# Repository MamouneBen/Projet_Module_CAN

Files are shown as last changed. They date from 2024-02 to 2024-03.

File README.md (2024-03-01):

# Logiciel :
**contient tous les éléments logiciels/programmations de ce projet**
-envoie de trame CAN
-conversion analogique

# Matériel : 
**contient tous les éléments physique de ce projet.**
-PCB
-Liste capteurs
-Liste pièces

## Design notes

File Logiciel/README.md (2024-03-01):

# ESP32-C3_Sender
code : c
framework : platformino
description : envoie can sur en c 

# ESP32Arduino
code : arduino (c++)
framework : platformino
description : envoie can sur en c++

# MCP3221
code : arduino (c++)
framework : platformino
description : conversion analogique à nunérique

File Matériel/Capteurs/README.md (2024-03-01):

# Capteurs 0-5V automobile
download

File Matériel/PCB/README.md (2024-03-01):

# PCB
framework : kicad 7.0

CapturePCB

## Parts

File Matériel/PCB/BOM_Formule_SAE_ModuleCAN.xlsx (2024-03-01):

Bill of Material
Board | Module_CAN |  | Concepteur Principal |  | Carl-Dominic Aubin |  |  | 1 | 00
Cours | Projet_Fin_DEC |  | Date du projet |  | 2024-03-01
Département | Technologies du génie électrique |  | Date de génération du BOM |  | 3/1/2024
Révision | 1.00 |  | Heure de génération du BOM |  | 10:55 AM
Nombre de PCB | 1 |  | Variant |  | None
Item Number | Designator | Layer | Description | Comment | #Column Name Error:' Package / Case | #Column Name Error:' Supplier 1 | #Column Name Error:' Supplier Part Number 1 | Quantity | Quantity Total | #Column Name Error:' Note
1 | C16 | Top | CAP ALUM 100UF 20% 50V SMD | 100 uF |  |  |  |  | 0
2 | C1, C5, C6, C15 | Top/Bot | Chip Capacitor, 10 uF, +/- 10%, 50 V, -55 to 125 degC, 0603 (1608 Metric), RoHS, Tape and Reel | 10 uF |  |  |  |  | 0
3 | C14 | Top | Conductive Polymer Aluminum Solid Capacitors (OS-CON) 68uF ±20% 50V RADIAL SMT 10x12.6mm | 68 uF |  |  |  |  | 0
4 | C12, C13 | Top | Capacitor; Ceramic; Cap; 47.0pF; Tol 5%; SMT; Vol-Rtg 50V; C0G; Tape and Reel | 47 pF |  |  |  |  | 0
5 | C3, C7, C8, C9, C10, C11 | Top/Bot | CAP CER 0.01UF 50V X7R 0805 | 0,1 uF |  |  |  |  | 0
6 | C7, C8 | Top | CAP CER 100PF 50V C0G/NPO 0805 | 100 pF |  |  |  |  | 0
7 | D1 | Top | DIODE SCHOTTKY 40V 1A SOD123F | SS14FL |  |  |  |  | 0
8 | FB1 | Bot | 120 Ohms @ 100 MHz 1 Power Line Ferrite Bead 0603 (1608 Metric) 3A 30mOhm | BLM18KG121TZ1D |  |  |  |  | 0
9 | J1, J2, J3 | Top | Connector_PinSocket_2.54mm:PinSocket_1x04_P2.54mm_Vertical | Conn_01x04_Socket |  |  |  |  | 0
10 | L1 | Top | Inductor Power Unshielded Wirewound 47uH 20% 100KHz 1.8A 0.14Ohm DCR T/R | NPI31W470MTRF |  |  |  |  | 0
11 | R1 | Top | Thin Film Resistors - SMD CPF 0805 91R 0.1% 25PPM 1K RL | 91 OMHS |  |  |  |  | 0
12 | R2 | Top | Thin Film Resistors - SMD CPF 0805 150R 0.1% 25PPM 1K RL | 150 OMHS |  |  |  |  | 0
13 | R3 | Top | Thin Film Resistors - SMD CPF 0805 150R 0.1% 25PPM 1K RL | 330 OMHS |  |  |  |  | 0
14 | R4, R5, R6, R8, R9 | Top/Bot | Thin Film Resistors - SMD CPF 0805 4700R 0.1% 25PPM 1K RL | 4700 OMHS |  |  |  |  | 0
15 | R7 | Top | Thin Film Resistors - SMD CPF 0805 10 000R 0.1% 25PPM 1K RL | 10 000 OMHS |  |  |  |  | 0
16 | R10, R11 | Top | Thin Film Resistors - SMD CPF 0805 10R 0.1% 25PPM 1K RL | 10 OMHS |  |  |  |  | 0
17 | R12 | Top | Thin Film Resistors - SMD CPF 0805 120 0.1% 25PPM 1K RL | 120 OMHS |  |  |  |  | 0
18 | U1 | Bot | adc | MCP3221 |  |  |  |  | 0
19 | U2 | Top | level-shifter | TCA9517 |  |  |  |  | 0
20 | U3 | Bot | esp32microcontroller | XIAO ESP32C3 |  |  |  |  | 0
21 | U6 | Bot | can transceiver | TJA1051T |  |  |  |  | 0
22 | U7 | Bot | 5v regulator | LM2674M-5.0 |  |  |  |  | 0
23 | U5 | Top | 3.3v regulator | LM117 |  |  |  |  | 0
Commentaires ou instruction spécialies

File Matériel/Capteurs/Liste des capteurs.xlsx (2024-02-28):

Liste des capteurs |  |  |  |  |  |  |  |  |  |  |  |  | Types de boîtiers
 |  |  |  |  |  |  |  |  |  |  |  |  | Standalone
 |  |  |  |  |  |  |  |  |  |  |  |  | PCB
 | Capteurs critiques |  |  |  |  |  |  |  |  |  |  |  | Drive/moteur
 | Mesure | Type de capteur | Interface | Supply Voltage | Manufacturier | Modèle | Prix | Digikey? | Mouser? | Datasheet | Commentaires | Boîtier
 | Rotation du volant | Potentiomètre | Analogique | Max 42Vdc | KAZ Technologies | Steering Position Sensor for Kaz Steering Rack | 150$US | no | no | https://kaz-technologies.myshopify.com/products/steering-sensor | Pour le steering rack de KAZ | Standalone
 |  | Potentiomètre | Analogique | 4.5? | Aimsports |  |  | https://www.ebay.ca/itm/335121168719?hash=item4e06c7394f:g:ynkAAOSwwUxlr7XH |  | https://www.aimsports.com/download/doc/eng/sensors/Datasheet_CarBikeRotatoryPotentiometerSteering_10G_105_eng.pdf | 10kOhms
 |  | Encodeur | CAN | 9-32 Vdc | Danfoss | SASA Steering sensor | 729.23$CAD | no | no | https://assets.danfoss.com/documents/75887/AI152886482948en-000303.pdf | https://maplelanefarmservice.ca/shop/parts/agco/technology-products/aco-acz0001550/ | Standalone
 |  | Encodeur | Analogique | 4.5-5.5Vdc | CUI Devices | AMT 203-V | 71.25$CAD |  | https://www.mouser.ca/ProductDetail/CUI-Devices/AMT203-V?qs=WyjlAZoYn51vfiQSHOoysQ%3D%3D | https://www.mouser.ca/datasheet/2/670/amt20_v-1775926.pdf |  | Standalone
 | Inclinaison | Gyromètre | J1939 (CAN) |  | Trombetta | J1939 Gyro Inclinometer (99-0550) | 147.99$US | no | no | https://www.murcal.com/Trombetta-99-0550-Inclinometer
 | Accélération | Accéléromètre | CAN |  | PCS | 3-Axis Accelerometer Module | 220$US | no | no | https://www.zerogravityperformance.com/product/3-axis-accelerometer-module/
 | Inclinaison + Accélération | IMU | CAN |  | AEM | AEM V2 Vehicle Dynamics Module | 574.21 | no | no | https://www.limitlessmotorsports.ca/ems-components/282146-aem-vehicle-dynamics-module-v2.html | Accel, gyro + GPS | Standalone
 |  | IMU (chip) | I2C, SPI | 2-3.6V | ST | ASM330LHH | $22.97 | https://www.digikey.ca/en/products/detail/stmicroelectronics/ASM330LHHTR/9998421 | https://www.mouser.ca/ProductDetail/STMicroelectronics/ASM330LHHTR?qs=lc2O%252BfHJPVYgP8P9MzExKQ%3D%3D | https://www.mouser.ca/datasheet/2/389/asm330lhh-1848833.pdf | AEC-Q100 (3 modèles disponibles) | PCB
 | Température des moteurs | Thermocouple | Analogique | N/A | NXP Semiconductors | KTY 81-210 | N/A | N/A | N/A | https://www.nxp.com/docs/en/data-sheet/KTY81_SER.pdf | Intégrés dans EMRAX 188 | Drive/moteur
 | Puissance de sortie de l'accumulateur | FSAE Energy Meter | CAN2.0A | GLV | N/A | N/A | N/A | N/A | N/A | N/A | Fourni par la compétition, harnais à acheter | Standalone
 | Température du liquide de refroidissement de l'accumulateur | Coolant Temperature Sensor (CTS) | Analogique |  | Amphenol Thermometrics | WTF083B001 | $11.68 | https://www.digikey.com/en/products/detail/amphenol-advanced-sensors/WTF083B001/10492361 |  | https://media.digikey.com/pdf/Data%20Sheets/Thermometrics%20Global%20Business%20PDFs/AAS-920-695A-Thermometrics-CTS-062017-web%20(4).pdf | Favoriser un sensor qui combine temperature et pression tel que le Ge-2099
 | Température et pression du liquide de refroidissement de l'accumulateur | SENSOR MULT PRESSURE/TEMP | Analogique | 5V, 4.5-5.5V | Amphenol advance sensors | GE-2099 | 94.33 | https://www.digikey.ca/en/products/detail/amphenol-advanced-sensors/GE-2099/16023973 |  | https://www.amphenol-sensors.com/hubfs/AAS-920-792B-Thermometrics-ComboSensor-082621-web.pdf
 | Position de la pédale d'accélérateur | Potentiomètre | Analogique, CAN, CANOPEN, SPI, PWM | 5V, 7-15V | Piher (Amphenol) | PST-360 | $98.85 |  | https://www.mouser.ca/ProductDetail/Amphenol-Piher/PST360G2-2AA-C0002-ERA360-05K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 | https://www.mouser.ca/datasheet/2/18/1/PST_360-1499208.pdf |  | Standalone
 | Position de la pédale de frein | Potentiomètre | Analogique, CAN, CANOPEN, SPI, PWM | 5V, 7-15V | Piher (Amphenol) | PST-360 | $98.85 |  | https://www.mouser.ca/ProductDetail/Amphenol-Piher/PST360G2-2AA-C0002-ERA360-05K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 | https://www.mouser.ca/datasheet/2/18/1/PST_360-1499208.pdf |  | Standalone
 | Déplacement de la suspension | Potentiomètre (shock) | Analogique |  | The sensor connection | Shock absorber suspension travel sensor - potentiometer | 180$ (0-3in de travel)
 | Pression freins | Pression sensor | Analogique | 4.75V à 5.25V | Bosch | PSS-140 | 179$ | https://www.motorsportselectronics.com/products/bosch-140-bar-pressure-sensor?variant=39347657605302 |  | https://www.bosch-motorsport.com/content/downloads/Raceparts/Resources/pdf/Data%20Sheet_351937803_Pressure_Sensor_Fluid_PSS-140/260/420/600.pdf | Entre 1500 et 2000psi (à confirmer avec dynamique)

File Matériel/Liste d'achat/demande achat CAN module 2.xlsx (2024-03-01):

Titre du projet
Formule SAE CAN (UdeS)
Demandeur(s) : Prof responsabe et étudiants
Carl-Dominic Aubin
Moment où le matériel est NÉCESSAIRE
Le plutôt possible
Identification des cours qui sont impactés
247-69P-SH
Lien(s) vers document de soumission (si applicable)
-
Liste des éléments associés
Description | Prix unitaire | Taux change (1 par défaut $Can) | Quantité demandée | Total item | Fournisseur | # Modèle pour commande | Hyperlien pour commande (si disponible) ou soumission | Commentaires et/ou autres informations | Colonne réservée pour suivi des commandes
FERRITE BEAD 120 OHM 0603 1LN | $0.840 | 1.00 | 20 | $16.80 | digikey | BLM18KG121TZ1D | https://www.digikey.com/en/products/detail/murata-electronics/BLM18KG121TZ1D/7363244
Connecteur CAN 4 pins | $2.610 | 1.00 | 16 | $41.76 | digikey | 889-1479-ND | https://www.digikey.ca/en/products/detail/amphenol-sine-systems-corp/ATM04-4P/5227552
Connecteur CAN 3 pins | $2.350 | 1.00 | 8 | $18.80 | digikey | 889-1478-ND | https://www.digikey.ca/en/products/detail/amphenol-sine-systems-corp/ATM04-3P/5227551
condensateur 100uF | $1.192 | 1.00 | 20 | $23.84 | digikey | EEE-FH1H101L | https://www.digikey.ca/en/products/detail/panasonic-electronic-components/EEE-FH1H101L/20372560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
condensateur 68uF | $0.682 | 1.00 | 20 | $13.64 | digikey | EEE-FN1H680XP | https://www.digikey.ca/en/products/detail/panasonic-electronic-components/EEE-FN1H680XP/11656970
bobine 47 uH | $0.495 | 1.00 | 20 | $9.90 | arrow | NPI31W470MTRF | https://www.arrow.com/en/products/npi31w470mtrf/nic-components
diode ss14fl | $0.234 | 1.00 | 20 | $4.68 | digikey | 1N5819W | https://www.digikey.ca/en/products/detail/smc-diode-solutions/1N5819W/15964243 | original part is discontinued this is replacement
lm2674 | $4.817 | 1.00 | 20 | $96.34 | digikey | LM2674MX-5.0/NOPB | https://www.digikey.ca/en/products/detail/texas-instruments/LM2674MX-5-0-NOPB/366903
 |  | 1.00 |  | $0.00
 |  | 1.00 |  | $0.00
 |  |  | Total sans taxes | $0.00
 |  |  | Taxe 7% | $0.00
 |  |  | Total avec taxes | $0.00
 | : pièces ajoutées

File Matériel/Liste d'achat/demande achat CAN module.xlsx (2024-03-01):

Titre du projet
Formule SAE CAN (UdeS)
Demandeur(s) : Prof responsabe et étudiants
Carl-Dominic Aubin
Moment où le matériel est NÉCESSAIRE
Le plutôt possible
Identification des cours qui sont impactés
247-69P-SH
Lien(s) vers document de soumission (si applicable)
-
Liste des éléments associés
Description | Prix unitaire | Taux change (1 par défaut $Can) | Quantité demandée | Total item | Fournisseur | # Modèle pour commande | Hyperlien pour commande (si disponible) ou soumission | Commentaires et/ou autres informations | Colonne réservée pour suivi des commandes
MCP3221 | $2.770 | 1.00 | 10 | $27.70 | mouser | 579-MCP3221A5T-E/OT | https://www.mouser.ca/ProductDetail/Microchip-Technology/MCP3221A5T-E-OT?qs=InakTnyiSK9lljladcdZHQ%3D%3D&mgh=1 | adc i2c
TCA9517 | $1.567 | 1.00 | 10 | $15.67 | digikey | TCA9517DGKR | https://www.digikey.ca/en/products/detail/texas-instruments/TCA9517DGKR/4135104 | level shifter
TJA1051T | $2.140 | 1.00 | 10 | $21.40 | digikey | TJA1051T/E | https://www.digikey.ca/en/products/detail/nxp-usa-inc./TJA1051T%2FE,118/2803571?productid=2803571&gad_source=1 | can transceiver
Seeed Studio XIAO ESP32C3 | $4.200 | 1.00 | 10 | $42.00 |  | - | https://www.seeedstudio.com/Seeed-XIAO-ESP32C3-p-5431.html
Connecteur CAN 4 pins | $2.610 | 1.00 | 16 | $41.76 | digikey | 889-1479-ND | https://www.digikey.ca/en/products/detail/amphenol-sine-systems-corp/ATM04-4P/5227552
Connecteur CAN 3 pins | $2.350 | 1.00 | 8 | $18.80 | digikey | 889-1478-ND | https://www.digikey.ca/en/products/detail/amphenol-sine-systems-corp/ATM04-3P/5227551
condensateur 100uF | $1.192 | 1.00 | 10 | $11.92 | digikey | EEE-FH1H101L | https://www.digikey.ca/en/products/detail/panasonic-electronic-components/EEE-FH1H101L/20372560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
condensateur 68uF | $0.682 | 1.00 | 10 | $6.82 | digikey | EEE-FN1H680XP | https://www.digikey.ca/en/products/detail/panasonic-electronic-components/EEE-FN1H680XP/11656970
bobine 47 uH | $0.495 | 1.00 | 10 | $4.95 | arrow | NPI31W470MTRF | https://www.arrow.com/en/products/npi31w470mtrf/nic-components
diode ss14fl | $0.234 | 1.00 | 10 | $2.34 | digikey | 1N5819W | https://www.digikey.ca/en/products/detail/smc-diode-solutions/1N5819W/15964243 | original part is discontinued this is replacement
lm2674 | $4.817 | 1.00 | 10 | $48.17 | digikey | LM2674MX-5.0/NOPB | https://www.digikey.ca/en/products/detail/texas-instruments/LM2674MX-5-0-NOPB/366903
 |  | 1.00 |  | $0.00
 |  | 1.00 |  | $0.00
 |  |  | Total sans taxes | $64.77
 |  |  | Taxe 7% | $4.53
 |  |  | Total avec taxes | $69.30
 | : pièces ajoutées

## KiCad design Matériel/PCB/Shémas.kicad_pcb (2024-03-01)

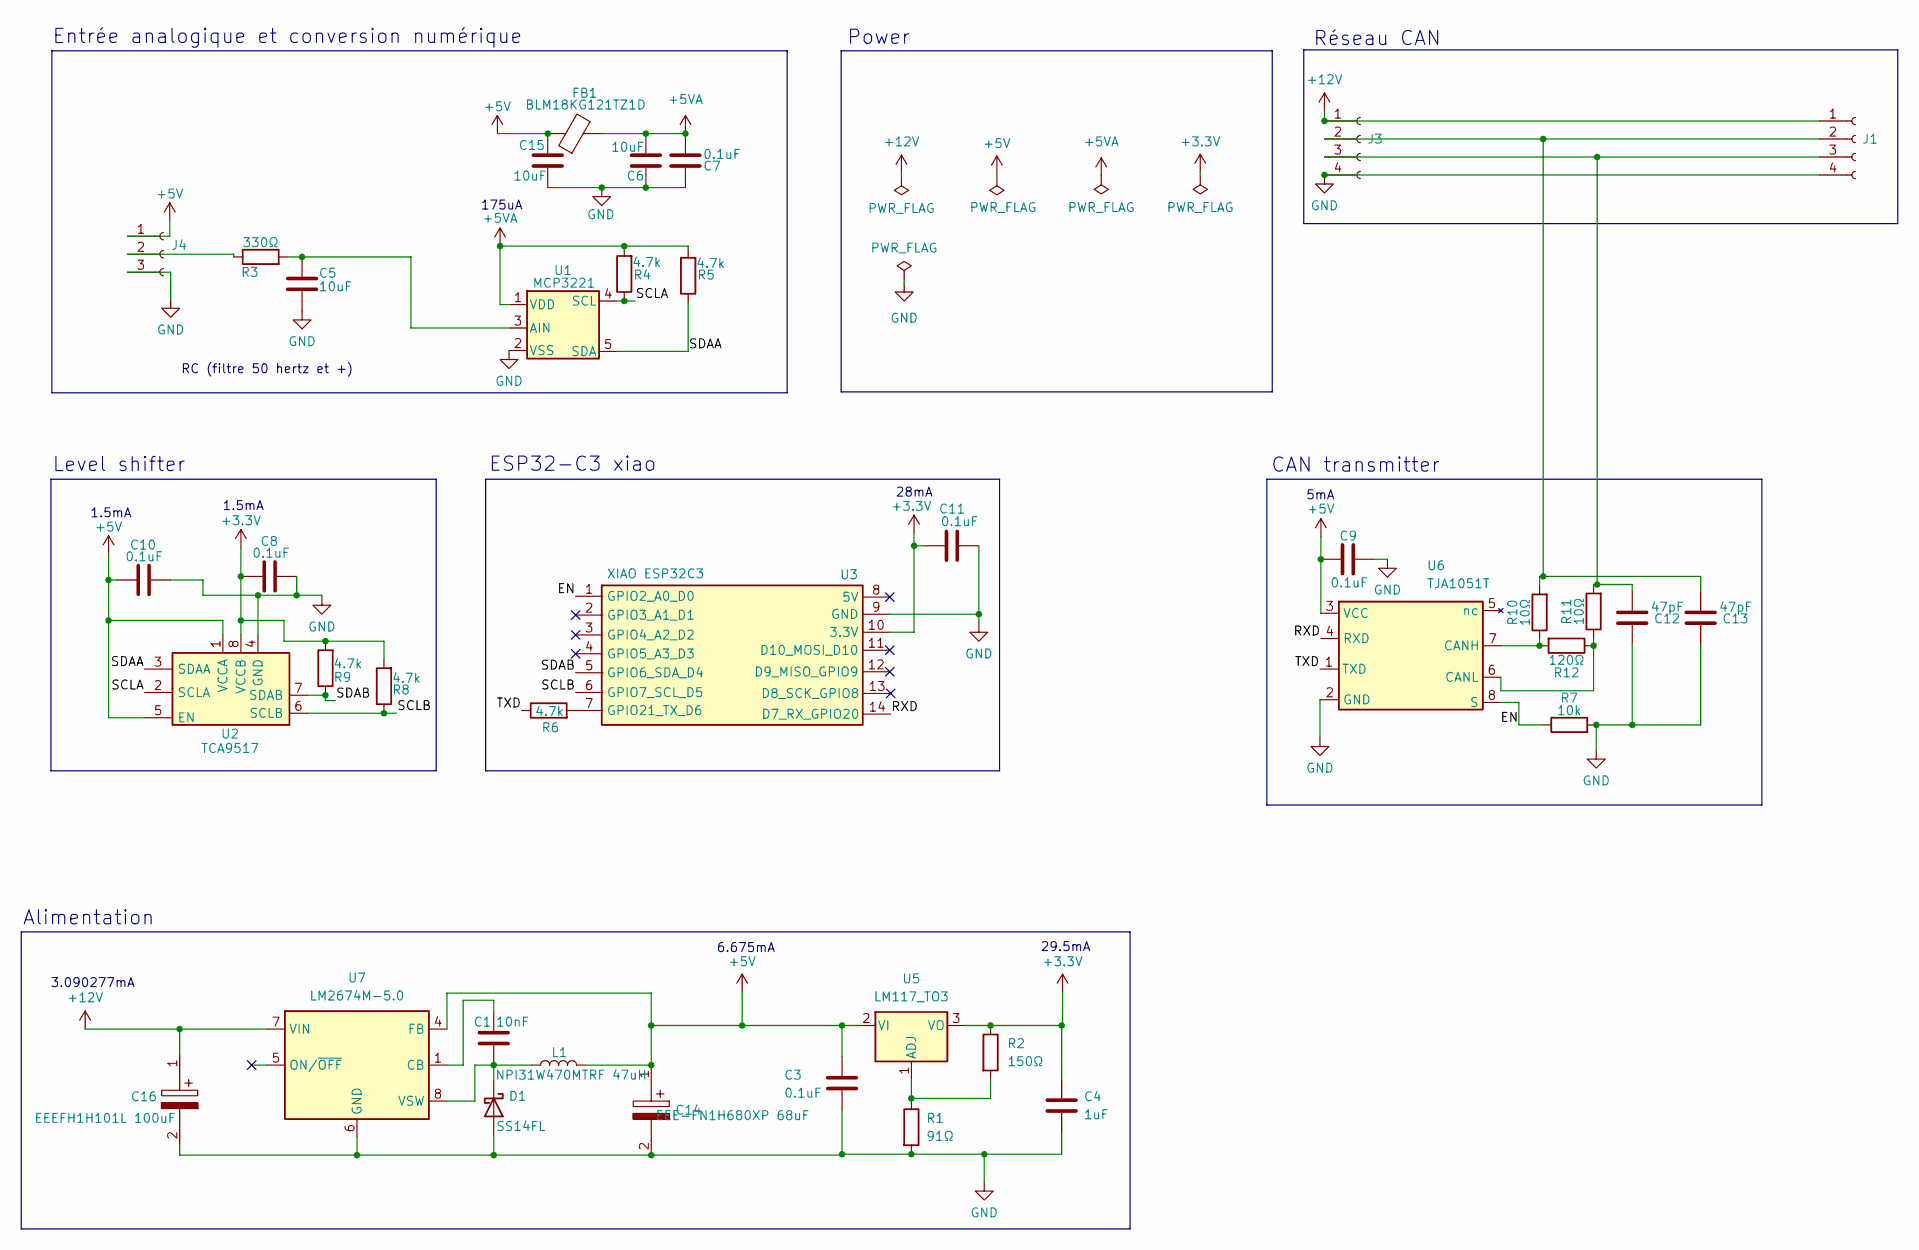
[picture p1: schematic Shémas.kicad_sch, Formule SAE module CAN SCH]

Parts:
C1: 10nF; C_0805_2012Metric_Pad1.18x1.45mm_HandSolder
C3, C7, C8, C9, C10, C11: 0.1uF; C_0805_2012Metric_Pad1.18x1.45mm_HandSolder
C4: 1uF; C_0805_2012Metric_Pad1.18x1.45mm_HandSolder
C5, C6, C15: 10uF; C_0805_2012Metric_Pad1.18x1.45mm_HandSolder
C12, C13: 47pF; C_0805_2012Metric_Pad1.18x1.45mm_HandSolder
C14: EEE-FN1H680XP 68uF; CP_Elec_8x6.9; Manufacturer_Part_Number EEEFH1H101L
C16: EEEFH1H101L 100uF; EEETC1V470P; Manufacturer_Part_Number EEEFH1H101L
D1: SS14FL; D_SOD-123F
FB1: BLM18KG121TZ1D; C_0603_1608Metric
J1, J3: Conn_01x04_Socket; PinSocket_1x04_P2.54mm_Vertical
J4: Conn_01x03_Socket; PinSocket_1x03_P2.54mm_Vertical
L1: NPI31W470MTRF 47uH; L_Bourns-SRR1005
R1: 91Ω; C_0805_2012Metric_Pad1.18x1.45mm_HandSolder
R2: 150Ω; C_0805_2012Metric_Pad1.18x1.45mm_HandSolder
R3: 330Ω; C_0805_2012Metric_Pad1.18x1.45mm_HandSolder
R4, R5, R6, R8, R9: 4.7k; C_0805_2012Metric_Pad1.18x1.45mm_HandSolder
R7: 10k; C_0805_2012Metric_Pad1.18x1.45mm_HandSolder
R10, R11: 10Ω; C_0805_2012Metric_Pad1.18x1.45mm_HandSolder
R12: 120Ω; C_0805_2012Metric_Pad1.18x1.45mm_HandSolder
U1: MCP3221; TSOT-23-5
U2: TCA9517; SOIC-8_3.9x4.9mm_P1.27mm
U3: XIAO ESP32C3; xiao esp32-c3
U5: LM117_TO3; SOT-223-3_TabPin2
U6: TJA1051T; SOIC-8_3.9x4.9mm_P1.27mm
U7: LM2674M-5.0; SOIC-8_3.9x4.9mm_P1.27mm

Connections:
+3.3V: C4.1, C8.2, C11.2, R2.1, R8.2, R9.2, U2.8 (VCCB), U3.10 (3.3V), U5.3 (VO)
+5V: C3.1, C9.1, C10.2, C14.1, C15.1, FB1.1, J4.1, L1.2, U2.1 (VCCA), U2.5 (EN), U5.2 (VI), U6.3 (VCC), U7.4 (FB)
+5VA: C6.2, C7.1, FB1.2, R4.2, R5.2, U1.1 (VDD)
+12V: C16.1, J1.1, J3.1, U7.7 (VIN)
/EN: R7.1, U3.1 (GPIO2_A0_D0), U6.8 (S)
/RXD: U3.14 (D7_RX_GPIO20), U6.4 (RXD)
/SCLA: R4.1, U1.4 (SCL), U2.2 (SCLA)
/SCLB: R8.1, U2.6 (SCLB), U3.6 (GPIO7_SCL_D5)
/SDAA: R5.1, U1.5 (SDA), U2.3 (SDAA)
/SDAB: R9.1, U2.7 (SDAB), U3.5 (GPIO6_SDA_D4)
/TXD: R6.1, U6.1 (TXD)
GND: C3.2, C4.2, C5.2, C6.1, C7.2, C8.1, C9.2, C10.1, C11.1, C12.1, C13.1, C14.2, C15.2, C16.2, D1.2 (A), J1.4, J3.4, J4.3, R1.2, R7.2, U1.2 (VSS), U2.4 (GND), U3.9 (GND), U6.2 (GND), U7.6 (GND)
unnamed: C1.1, D1.1 (K), L1.1, U7.8 (VSW)
unnamed: C13.2, J1.2, J3.2, R10.2
unnamed: C12.2, J1.3, J3.3, R11.2
unnamed: J4.2, R3.1
unnamed: C5.1, R3.2, U1.3 (AIN)
unnamed: R6.2, U3.7 (GPIO21_TX_D6)
unnamed: R1.1, R2.2, U5.1 (ADJ)
unnamed: R10.1, R12.2, U6.7 (CANH)
unnamed: R11.1, R12.1, U6.6 (CANL)
unnamed: C1.2, U7.1 (CB)

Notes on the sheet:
6.675mA
3.090277mA
1.5mA
Alimentation
29.5mA
Power
Entrée analogique et conversion numérique
ESP32-C3 xiao
RC (filtre 50 hertz et +)
Réseau CAN
Level shifter
28mA
CAN transmitter
5mA
175uA

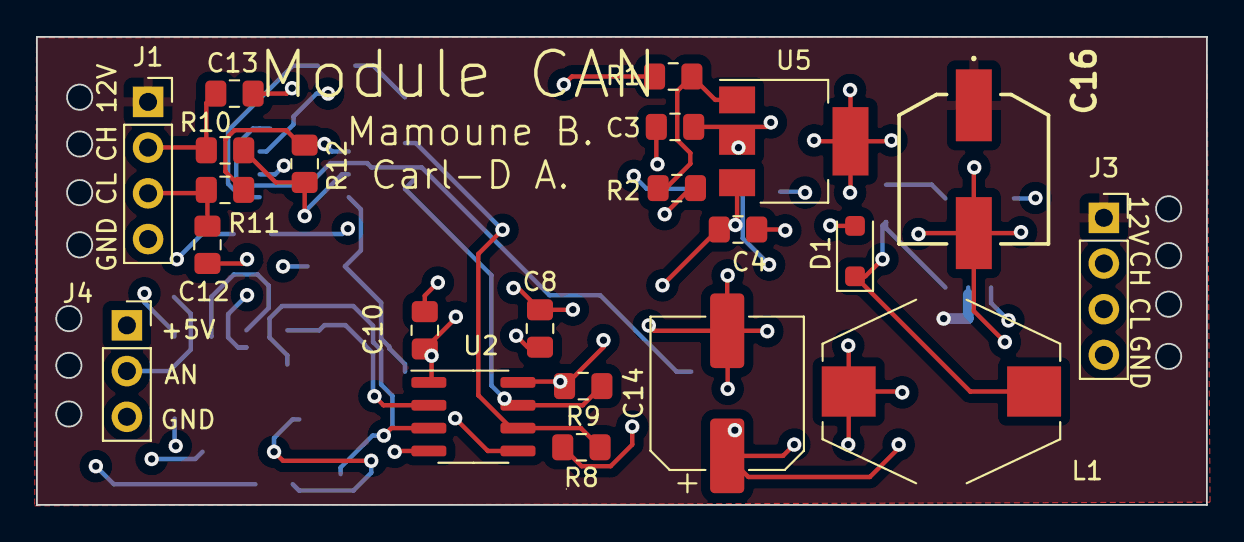
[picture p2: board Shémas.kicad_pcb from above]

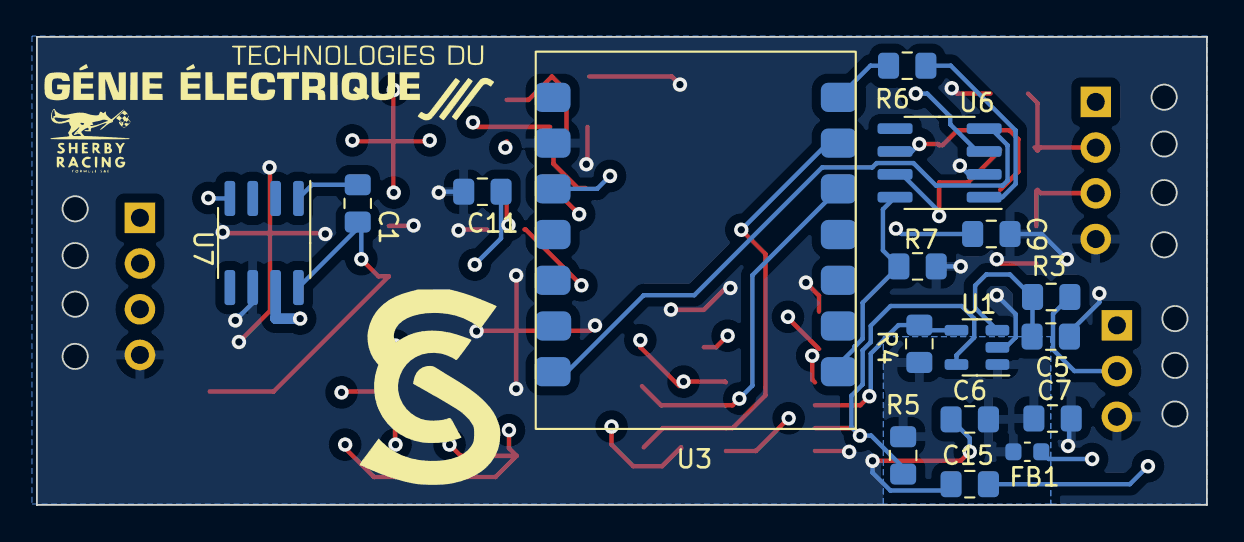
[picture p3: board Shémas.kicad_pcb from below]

Board: 4 copper layers, 65.0 x 26.0 mm, 39 parts (17 on the bottom side), 22 nets.

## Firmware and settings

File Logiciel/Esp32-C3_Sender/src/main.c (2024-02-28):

#include <stdio.h>
#include "freertos/FreeRTOS.h"
#include "freertos/task.h"
#include "driver/adc.h"
#include "driver/twai.h"

#define POT_PIN 0 // Remplacez par le numéro de broche GPIO réelle à laquelle le potentiomètre est connecté

void potentiometer_can_task(void *pvParameter) {
    // Initialisation de la configuration CAN
    twai_general_config_t g_config = TWAI_GENERAL_CONFIG_DEFAULT(GPIO_NUM_1, GPIO_NUM_6, TWAI_MODE_NORMAL);
    twai_timing_config_t t_config = TWAI_TIMING_CONFIG_500KBITS();
    twai_filter_config_t f_config = TWAI_FILTER_CONFIG_ACCEPT_ALL();

    // Installation du pilote CAN
    if (twai_driver_install(&g_config, &t_config, &f_config) != ESP_OK) {
        printf("Échec de l'installation du pilote CAN\n");
        vTaskDelete(NULL);
    }

    // Démarrage du pilote CAN
    if (twai_start() != ESP_OK) {
        printf("Échec du démarrage du pilote CAN\n");
        vTaskDelete(NULL);
    }

    adc1_config_width(ADC_WIDTH_BIT_12);
    adc1_config_channel_atten(ADC1_CHANNEL_0, ADC_ATTEN_DB_11);

    while (1) {
        // Mesurer la tension du potentiomètre
        int pot_value = adc1_get_raw(ADC1_CHANNEL_0);
        float voltage = pot_value * (3.0 / 4095.0); //3.3
        printf("Valeur du potentiomètre : %d, Tension : %.2fV\n", pot_value, voltage);

        // Convertir la valeur en une chaîne de caractères (4 digits)
        char bufferPotValue[5]; // 4 digits + le caractère de fin de chaîne
        snprintf(bufferPotValue, sizeof(bufferPotValue), "%04d", pot_value);

        // Configurer le message CAN à transmettre
        twai_message_t adc_message;
        adc_message.identifier = 0xB;
        adc_message.data_length_code = 8;
        adc_message.rtr = 0;

        // Copier chaque caractère du buffer dans le message CAN
        for (int i = 0; i < 4; i++) {
            adc_message.data[i] = bufferPotValue[i];
        }

        adc_message.data[4] = 0; // Ajoutez d'autres données si nécessaire
        adc_message.data[5] = 0;
        adc_message.data[6] = 0;
        adc_message.data[7] = 0;

        // Mettre en file d'attente le message pour la transmission
        if (twai_transmit(&adc_message, pdMS_TO_TICKS(1000)) == ESP_OK) {
            printf("Message mis en file d'attente pour la transmission\n");
        } else {
            printf("Échec de la mise en file d'attente du message pour la transmission\n");
        }

        // Délai de 2 secondes entre chaque mesure
        vTaskDelay(pdMS_TO_TICKS(500));
    }
}

void app_main() {
    xTaskCreate(potentiometer_can_task, "potentiometer_can_task", 2048, NULL, 5, NULL);
}


/*#include "driver/gpio.h"
#include "driver/twai.h"
#include "freertos/FreeRTOS.h"
#include "freertos/task.h"

void app_main()
{
    // Initialize configuration structures using macro initializers
    twai_general_config_t g_config = TWAI_GENERAL_CONFIG_DEFAULT(GPIO_NUM_1, GPIO_NUM_6, TWAI_MODE_NORMAL);
    twai_timing_config_t t_config = TWAI_TIMING_CONFIG_500KBITS();
    twai_filter_config_t f_config = TWAI_FILTER_CONFIG_ACCEPT_ALL();

    // Install TWAI driver
    if (twai_driver_install(&g_config, &t_config, &f_config) == ESP_OK) {
        printf("Driver installed\n");
    } else {
        printf("Failed to install driver\n");
        return;
    }

    // Start TWAI driver
    if (twai_start() == ESP_OK) {
        printf("Driver started\n");
    } else {
        printf("Failed to start driver\n");
        return;
    }

    // Delay for 2000 ms
    vTaskDelay(pdMS_TO_TICKS(2000));

    // Configure message to transmit
    twai_message_t message;
    message.identifier = 0xAAAA;
    message.data_length_code = 8;
    message.rtr = 0;
    message.data[0] = 'h';
    message.data[1] = 'e';
    message.data[2] = 'l';
    message.data[3] = 'l';
    message.data[4] = 'o';
    message.data[5] = 'w';
    message.data[6] = 'o';
    message.data[7] = 'r';

    // Queue message for transmission
    if (twai_transmit(&message, pdMS_TO_TICKS(1000)) == ESP_OK) {
        printf("Message queued for transmission\n");
    } else {
        printf("Failed to queue message for transmission\n");
    }
}*/

/*#include "freertos/FreeRTOS.h"
#include "freertos/task.h"
#include "driver/adc.h"

#define POT_PIN GPIO_NUM_0 // Utilisation du canal ADC correspondant à GPIO_NUM_34

void adc_task(void *arg) {
    int adc_reading;
    int voltage;

    // Configuration de l'ADC
    adc1_config_width(ADC_WIDTH_BIT_12);
    adc1_config_channel_atten(POT_PIN, ADC_ATTEN_DB_11);

    while (1) {
        // Lecture de la valeur ADC
        adc_reading = adc1_get_raw(POT_PIN);

        // Conversion de la valeur ADC en tension
        voltage = adc_reading * (3.3 / 4095.0);

        // Impression des résultats sur la console
        printf(adc_reading);
        printf(voltage);

        vTaskDelay(pdMS_TO_TICKS(1000)); // Attendre 1 seconde entre chaque lecture
    }
}

void app_main() {
    // Création de la tâche ADC
    xTaskCreate(adc_task, "adc_task", 2048, NULL, 5, NULL);
}
*/


/*
#include "driver/gpio.h"
#include "driver/twai.h"
#include "freertos/FreeRTOS.h"
#include "freertos/task.h"

const int potPin3 = 34;  // GPIO 34 (Analog ADC1_CH6)
const int uartTxPin = GPIO_NUM_1;
const int uartRxPin = GPIO_NUM_6;

void setup_potentiometer() {
    // Configure the ADC
    adc1_config_width(ADC_WIDTH_BIT_12);
    adc1_config_channel_atten(ADC1_CHANNEL_6, ADC_ATTEN_DB_11);

    // Configure UART communication
    uart_config_t uart_config = {
        .baud_rate = 9600,
        .data_bits = UART_DATA_8_BITS,
        .parity    = UART_PARITY_DISABLE,
        .stop_bits = UART_STOP_BITS_1,
        .flow_ctrl = UART_HW_FLOWCTRL_DISABLE
    };
    uart_param_config(UART_NUM_1, &uart_config);
    uart_set_pin(UART_NUM_1, uartRxPin, uartTxPin, UART_PIN_NO_CHANGE, UART_PIN_NO_CHANGE);
    uart_driver_install(UART_NUM_1, 256, 0, 0, NULL, 0);
}

void app_main() {
    // Initialize configuration structures using macro initializers
    twai_general_config_t g_config = TWAI_GENERAL_CONFIG_DEFAULT(GPIO_NUM_1, GPIO_NUM_6, TWAI_MODE_NORMAL);
    twai_timing_config_t t_config = TWAI_TIMING_CONFIG_500KBITS();
    twai_filter_config_t f_config = TWAI_FILTER_CONFIG_ACCEPT_ALL();

    // Install TWAI driver
    if (twai_driver_install(&g_config, &t_config, &f_config) == ESP_OK) {
        printf("Driver installed\n");
    } else {
        printf("Failed to install driver\n");
        return;
    }

    // Start TWAI driver
    if (twai_start() == ESP_OK) {
        printf("Driver started\n");
    } else {
        printf("Failed to start driver\n");
        return;
    }

    // Setup potentiometer
    setup_potentiometer();

    while (1) {
        // Reading potentiometer value
        uint32_t potValue = adc1_get_raw(ADC1_CHANNEL_6);

        // Convert the ADC value to a voltage (assuming 3.3V reference voltage)
        float voltage = potValue * (3.3 / 4095.0);

        // Print the ADC value and the corresponding voltage
        printf("ADC Value: %d, Voltage: %.2f V\n", potValue, voltage);

        // Configure message to transmit
        twai_message_t message;
        message.identifier = 0x12345678;
        message.data_length_code = 8;
        message.data[0] = (uint8_t)(voltage);          // Assuming voltage is a float in the range [0, 255]
        message.data[1] = (uint8_t)((voltage * 10.0));  // Adjust multiplier as needed
        // Add more data bytes as needed

        // Queue message for transmission
        if (twai_transmit(&message, pdMS_TO_TICKS(1000)) == ESP_OK) {
            printf("Message queued for transmission\n");
        } else {
            printf("Failed to queue message for transmission\n");
        }

        vTaskDelay(pdMS_TO_TICKS(2000));
    }
}

*/

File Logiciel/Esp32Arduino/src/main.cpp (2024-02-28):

#include <Arduino.h>
#include <ESP32-TWAI-CAN.hpp>
#include <Wire.h>
#include "MCP3X21.h"  // https://github.com/pilotak/MCP3X21
// https://github.com/pilotak/MCP3X21/blob/master/examples/MCP3221/MCP3221.ino

/*
// Define CAN TX and RX pins
#define CAN_TX 1
#define CAN_RX 6

// Define MCP3428 I2C address
const uint8_t MCP3428_ADDRESS = 0x68;

void setup() {
    Serial.begin(115200);

    // Initialize I2C communication with specified pins
    Wire.begin(21, 22); // Adjust SDA and SCL pins as per your ESP32 board

    // Initialize CAN communication
    ESP32Can.setPins(CAN_TX, CAN_RX);
    ESP32Can.setRxQueueSize(5);
    ESP32Can.setTxQueueSize(5);
    ESP32Can.setSpeed(ESP32Can.convertSpeed(500));

    if (ESP32Can.begin()) {
        Serial.println("CAN bus started successfully!");
    } else {
        Serial.println("Failed to start CAN bus!");
    }
}

void sendPotentiometerValue(uint16_t potValue) {
    // Define CAN frame
    CanFrame potFrame = { 0 };
    potFrame.identifier = 0xB; // CAN ID
    potFrame.extd = 0;
    potFrame.data_length_code = 8;

    // Fill CAN frame data with potentiometer value
    uint8_t* bufferPotValue = reinterpret_cast<uint8_t*>(&potValue);
    for (int i = 0; i < 4; i++) {
        potFrame.data[i] = bufferPotValue[i];
    }

    // Send the CAN frame
    ESP32Can.writeFrame(potFrame);
}

void loop() {
    // Read data from MCP3428
    // Your code to read data from MCP3428 goes here
    // You need to implement the communication protocol for MCP3428
    // and obtain the ADC value

    // Once you obtain the ADC value, send it over CAN
    // For demonstration, let's assume 'result' is the ADC value
    uint16_t result = 0; // Update with your actual ADC value

    // Print the ADC value to serial monitor
    Serial.print("ADC Value: ");
    Serial.println(result);

    // Send the ADC value over CAN
    sendPotentiometerValue(result);

    // Delay before next iteration
    delay(1000);
}
*/

/*
void setup() {
  Serial.begin(115200);
  while (!Serial);

  Wire.begin();
  Serial.println("\nI2C Scanner");
}

void loop() {
  byte error, address;
  int devices = 0;

  Serial.println("Scanning...");

  for (address = 1; address < 127; address++) {
    Wire.beginTransmission(address);
    error = Wire.endTransmission();

    if (error == 0) {
      Serial.print("Device found at address 0x");
      if (address < 16)
        Serial.print("0");
      Serial.println(address, HEX);

      devices++;
    } else if (error == 4) {
      Serial.print("Unknown error at address 0x");
      if (address < 16)
        Serial.print("0");
      Serial.println(address, HEX);
    }
  }

  if (devices == 0)
    Serial.println("No I2C devices found");

  delay(5000); // Wait for 5 seconds before scanning again
}*/

//broches TX RX pour la communication CAN
#define CAN_TX 1
#define CAN_RX 6

const uint8_t address = 0x68; //0x6E
const uint16_t ref_voltage = 5000;  // 3.3v

MCP3221 mcp3221(address);

void setup() {
    Serial.begin(115200);
    Wire.begin(8, 9); // 1,2
    mcp3221.init(&Wire);

    /*#if defined(ESP8266) || defined(ESP32)
        Wire.begin(8, 9); // 1,2
        mcp3221.init(&Wire);
    #else
        mcp3221.init();
    #endif*/

    ESP32Can.setPins(CAN_TX, CAN_RX); // initialisation la communication CAN
    ESP32Can.setRxQueueSize(5);
    ESP32Can.setTxQueueSize(5);
    ESP32Can.setSpeed(ESP32Can.convertSpeed(500));

    if (ESP32Can.begin()) {
        Serial.println("Bus CAN démarré !");
    } else {
        Serial.println("Échec du démarrage du bus CAN !");
    }
}

void sendPotentiometerValue(uint16_t potValue) {

    CanFrame potFrame = { 0 };
    potFrame.identifier = 0xB; //ID
    potFrame.extd = 0;
    potFrame.data_length_code = 8;

    uint8_t* bufferPotValue = reinterpret_cast<uint8_t*>(&potValue); // copie chaque caractère du buffer dans le message CAN
    for (int i = 0; i < 4; i++) {
        potFrame.data[i] = bufferPotValue[i];
    }

    potFrame.data[4] = 0; 
    potFrame.data[5] = 0;
    potFrame.data[6] = 0;
    potFrame.data[7] = 0;

    ESP32Can.writeFrame(potFrame);
}

void loop() {
    uint16_t result = mcp3221.read();

    Serial.print(F("ADC: "));
    Serial.print(result);
    Serial.print(F(", mV: "));
    Serial.println(mcp3221.toVoltage(result, ref_voltage));

    sendPotentiometerValue(result); // envoi de la valeur du potentiomètre par CAN

    delay(1000);
}



/*
//broches TX RX pour la communication CAN
#define CAN_TX 1
#define CAN_RX 6

// trame de réception
CanFrame rxFrame;

void sendPotentiometerValue(uint16_t potValue) {
    CanFrame potFrame = { 0 };
    potFrame.identifier = 0xB; //ID
    potFrame.extd = 0;
    potFrame.data_length_code = 8;
    
   // uint8_t* bufferPotValue = reinterpret_cast<uint8_t*>(&potValue); // Copier chaque caractère du buffer dans le message CAN
  //  for (int i = 0; i < 4; i++) {
  //      potFrame.data[i] = bufferPotValue[i];
  //  } 
    
    potFrame.data[0] = (potValue >> 8) & 0xFF; // High byte
    potFrame.data[1] = potValue & 0xFF;        // Low byte
    potFrame.data[2] = 0;   
    potFrame.data[3] = 0;
    potFrame.data[4] = 0;
    potFrame.data[5] = 0;
    potFrame.data[6] = 0;
    potFrame.data[7] = 0;
    ESP32Can.writeFrame(potFrame);
}

void setup() {
    Serial.begin(115200);
    
    // Initialisation la communication CAN
    ESP32Can.setPins(CAN_TX, CAN_RX);
    ESP32Can.setRxQueueSize(5);
    ESP32Can.setTxQueueSize(5);
    ESP32Can.setSpeed(ESP32Can.convertSpeed(500));

    if (ESP32Can.begin()) {
        Serial.println("Bus CAN démarré !");
    } else {
        Serial.println("Échec du démarrage du bus CAN !");
    }
}

void loop() {
    static uint32_t lastMillis = 0;
    uint32_t currentMillis = millis();

    if (currentMillis - lastMillis > 500) { // Mesure toutes les 500ms
        lastMillis = currentMillis;
        uint16_t potValue = analogRead(A0); // Lire la valeur du potentiomètre
        float voltage = potValue * (3.0 / 4095.0);
        Serial.print("Valeur du potentiomètre : ");
        Serial.print(potValue);
        Serial.print(", Tension : ");
        Serial.println(voltage);
        sendPotentiometerValue(potValue); // Envoyer la valeur du potentiomètre par CAN
    }

    if (ESP32Can.readFrame(rxFrame, 100)) { // Lire une frame CAN
        Serial.print("Frame reçue : ");
        Serial.print(rxFrame.identifier, HEX);
        Serial.print(", Données : ");
        for (int i = 0; i < rxFrame.data_length_code; i++) {
            Serial.print(rxFrame.data[i], HEX);
            Serial.print(" ");
        }
        Serial.println();
    }
}


const uint8_t address = 0x4D;
const uint16_t ref_voltage = 5000;  // in mV

MCP3221 mcp3221(address);

void setup() {
    Serial.begin(115200);

#if defined(ESP8266) || defined(ESP32)
    Wire.begin(SDA, SCL);
    mcp3221.init(&Wire);
#else
    mcp3221.init();
#endif
}
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

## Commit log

2024-02-28 change directory
    github reconstruction
    [Shémas.kicad_pcb, Shémas.kicad_sch]
2024-02-28 Correction du pcb
    changemnet blm en 0603 et rx-rx et tx-tx
    [Shémas.kicad_pcb]
2024-02-28 ok
    ok
    [Shémas.kicad_pcb, Shémas.kicad_sch]
2024-02-28 PCB update
    [Shémas.kicad_sch]
2024-03-01 Mise à jours du PCB
    Ajout de consommation du courant
    -12v
    -5v
    -3.3v
    [Shémas.kicad_sch]
2024-03-01 Pcb + code esp32 receive
    gerber generate + recup du conne reception can
    [Shémas-12V_Cu.gbr, Shémas-AN_Cu.gbr, Shémas-B_Mask.gbr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]
2024-03-01 gerber
    ajout du zip gerber
    [Shémas-12V_Cu.gbr, Shémas-AN_Cu.gbr, Shémas-B_Mask.gbr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]
2024-03-01 Bom - pcb
    Ajout du bom pour le pcb
    [BOM_Formule_SAE_ModuleCAN.xlsx]
2024-03-01 2.0.1: Update main.cpp
    Code transmission fonctionnel: conversion ADC sur 12bits avec MCP3221 et envoi de message CAN avec TJA1050
2024-03-01 2.0.1: Update SRC/mian.cpp
    Mise à jour des fichiers
2024-03-01 Revert "Merge branch 'HIVER24' of https://github.com/MamouneBen/Projet_Module_CAN into HIVER24"
    This reverts commit 874f798376b48448e87766e90eeb9947adf93433, reversing
    changes made to a5d7c4e769dad0254442863986409e13f518113b.
    [main.cpp]
2024-03-01 Revert "2.0.1: Update SRC/mian.cpp"
    This reverts commit a5d7c4e769dad0254442863986409e13f518113b.
    [main.cpp]
